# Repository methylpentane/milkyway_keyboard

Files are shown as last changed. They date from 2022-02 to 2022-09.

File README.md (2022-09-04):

# milkyway 65% keyboard pcb & plate
This repository contains kicad file (PCB/schematic), no firmware here.

This repository based on [GL516 Design Template](https://github.com/Salicylic-acid3/GL516_Template) by Salicylic-acid3.

# feature
- 65% keyboard that neatly looks like Tsangan-layout.
- Several layout options on center area(milkyway-area).
    - macro
    - rotary encoders
    - numpad (with sacrificing symbol keys on righthand)
- Also there will be some layout options on R5.
    - split spacebars
    - one more rotary encoder
    - 8u & 10u spacebar 🤔

# supported layout
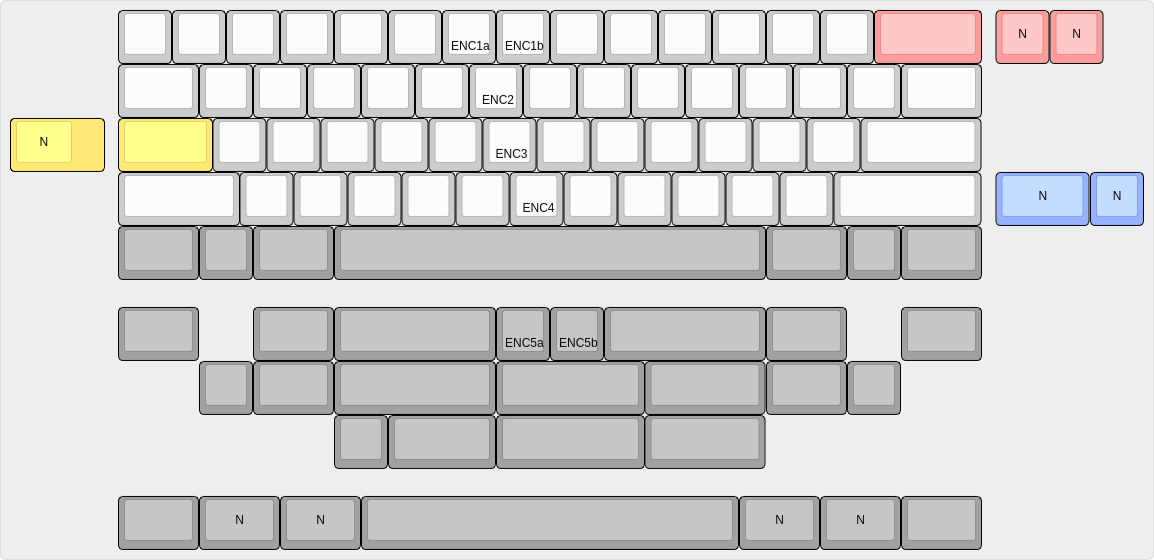
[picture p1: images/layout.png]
layout

- about keys that have "ENC" written, you can choose whether to implement keyswitch or encoder.
    - For ENC1a and ENC1b, only one of the encoders can be implemented. and the same for ENC5a and ENC5b.
- some layouts force northfacing switch (switch with "N")

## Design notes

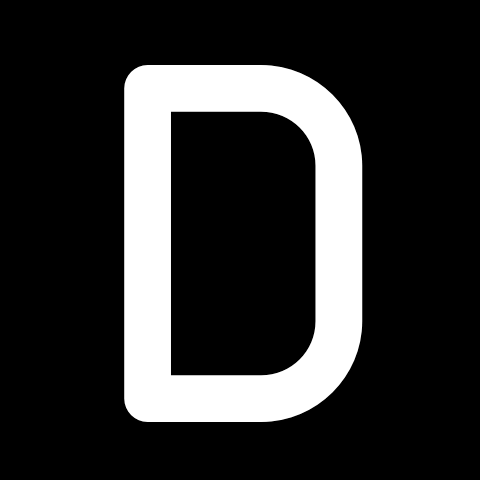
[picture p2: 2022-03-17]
images/D_label.png

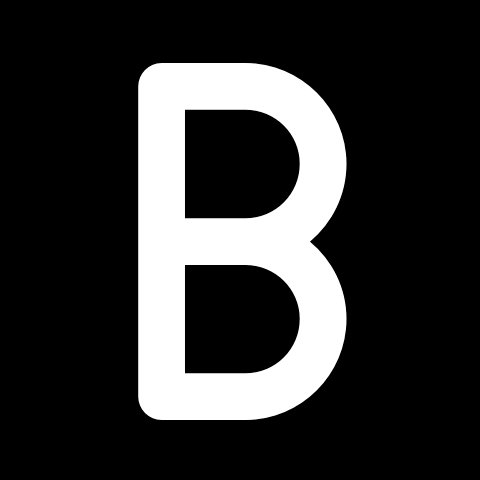
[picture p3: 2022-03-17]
images/B_label.png

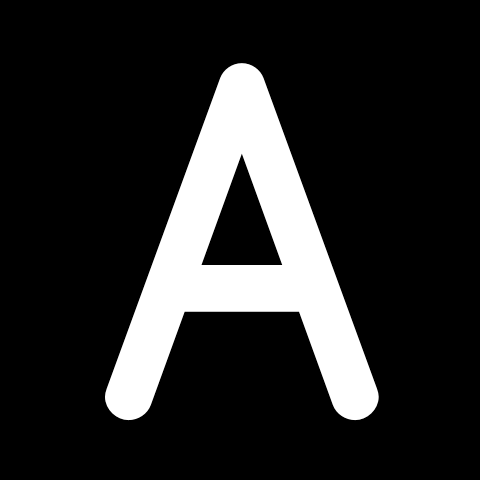
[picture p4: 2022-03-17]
images/A_label.png

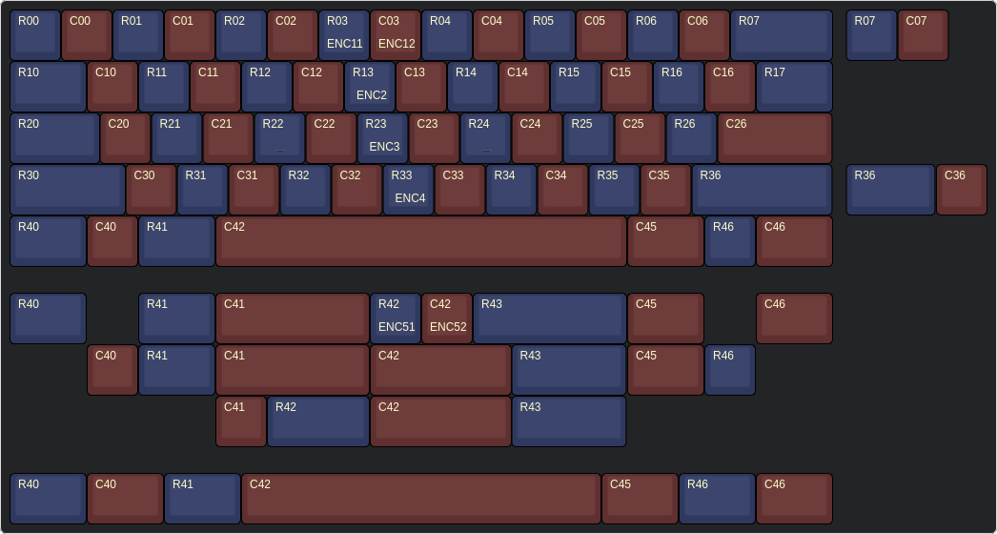
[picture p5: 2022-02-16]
images/layout_for_dev.png

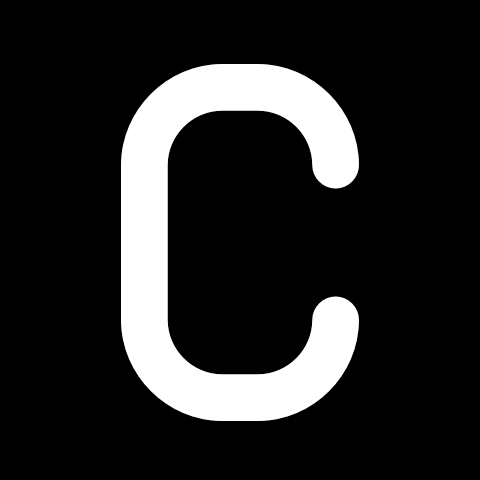
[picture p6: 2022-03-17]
images/C_label.png

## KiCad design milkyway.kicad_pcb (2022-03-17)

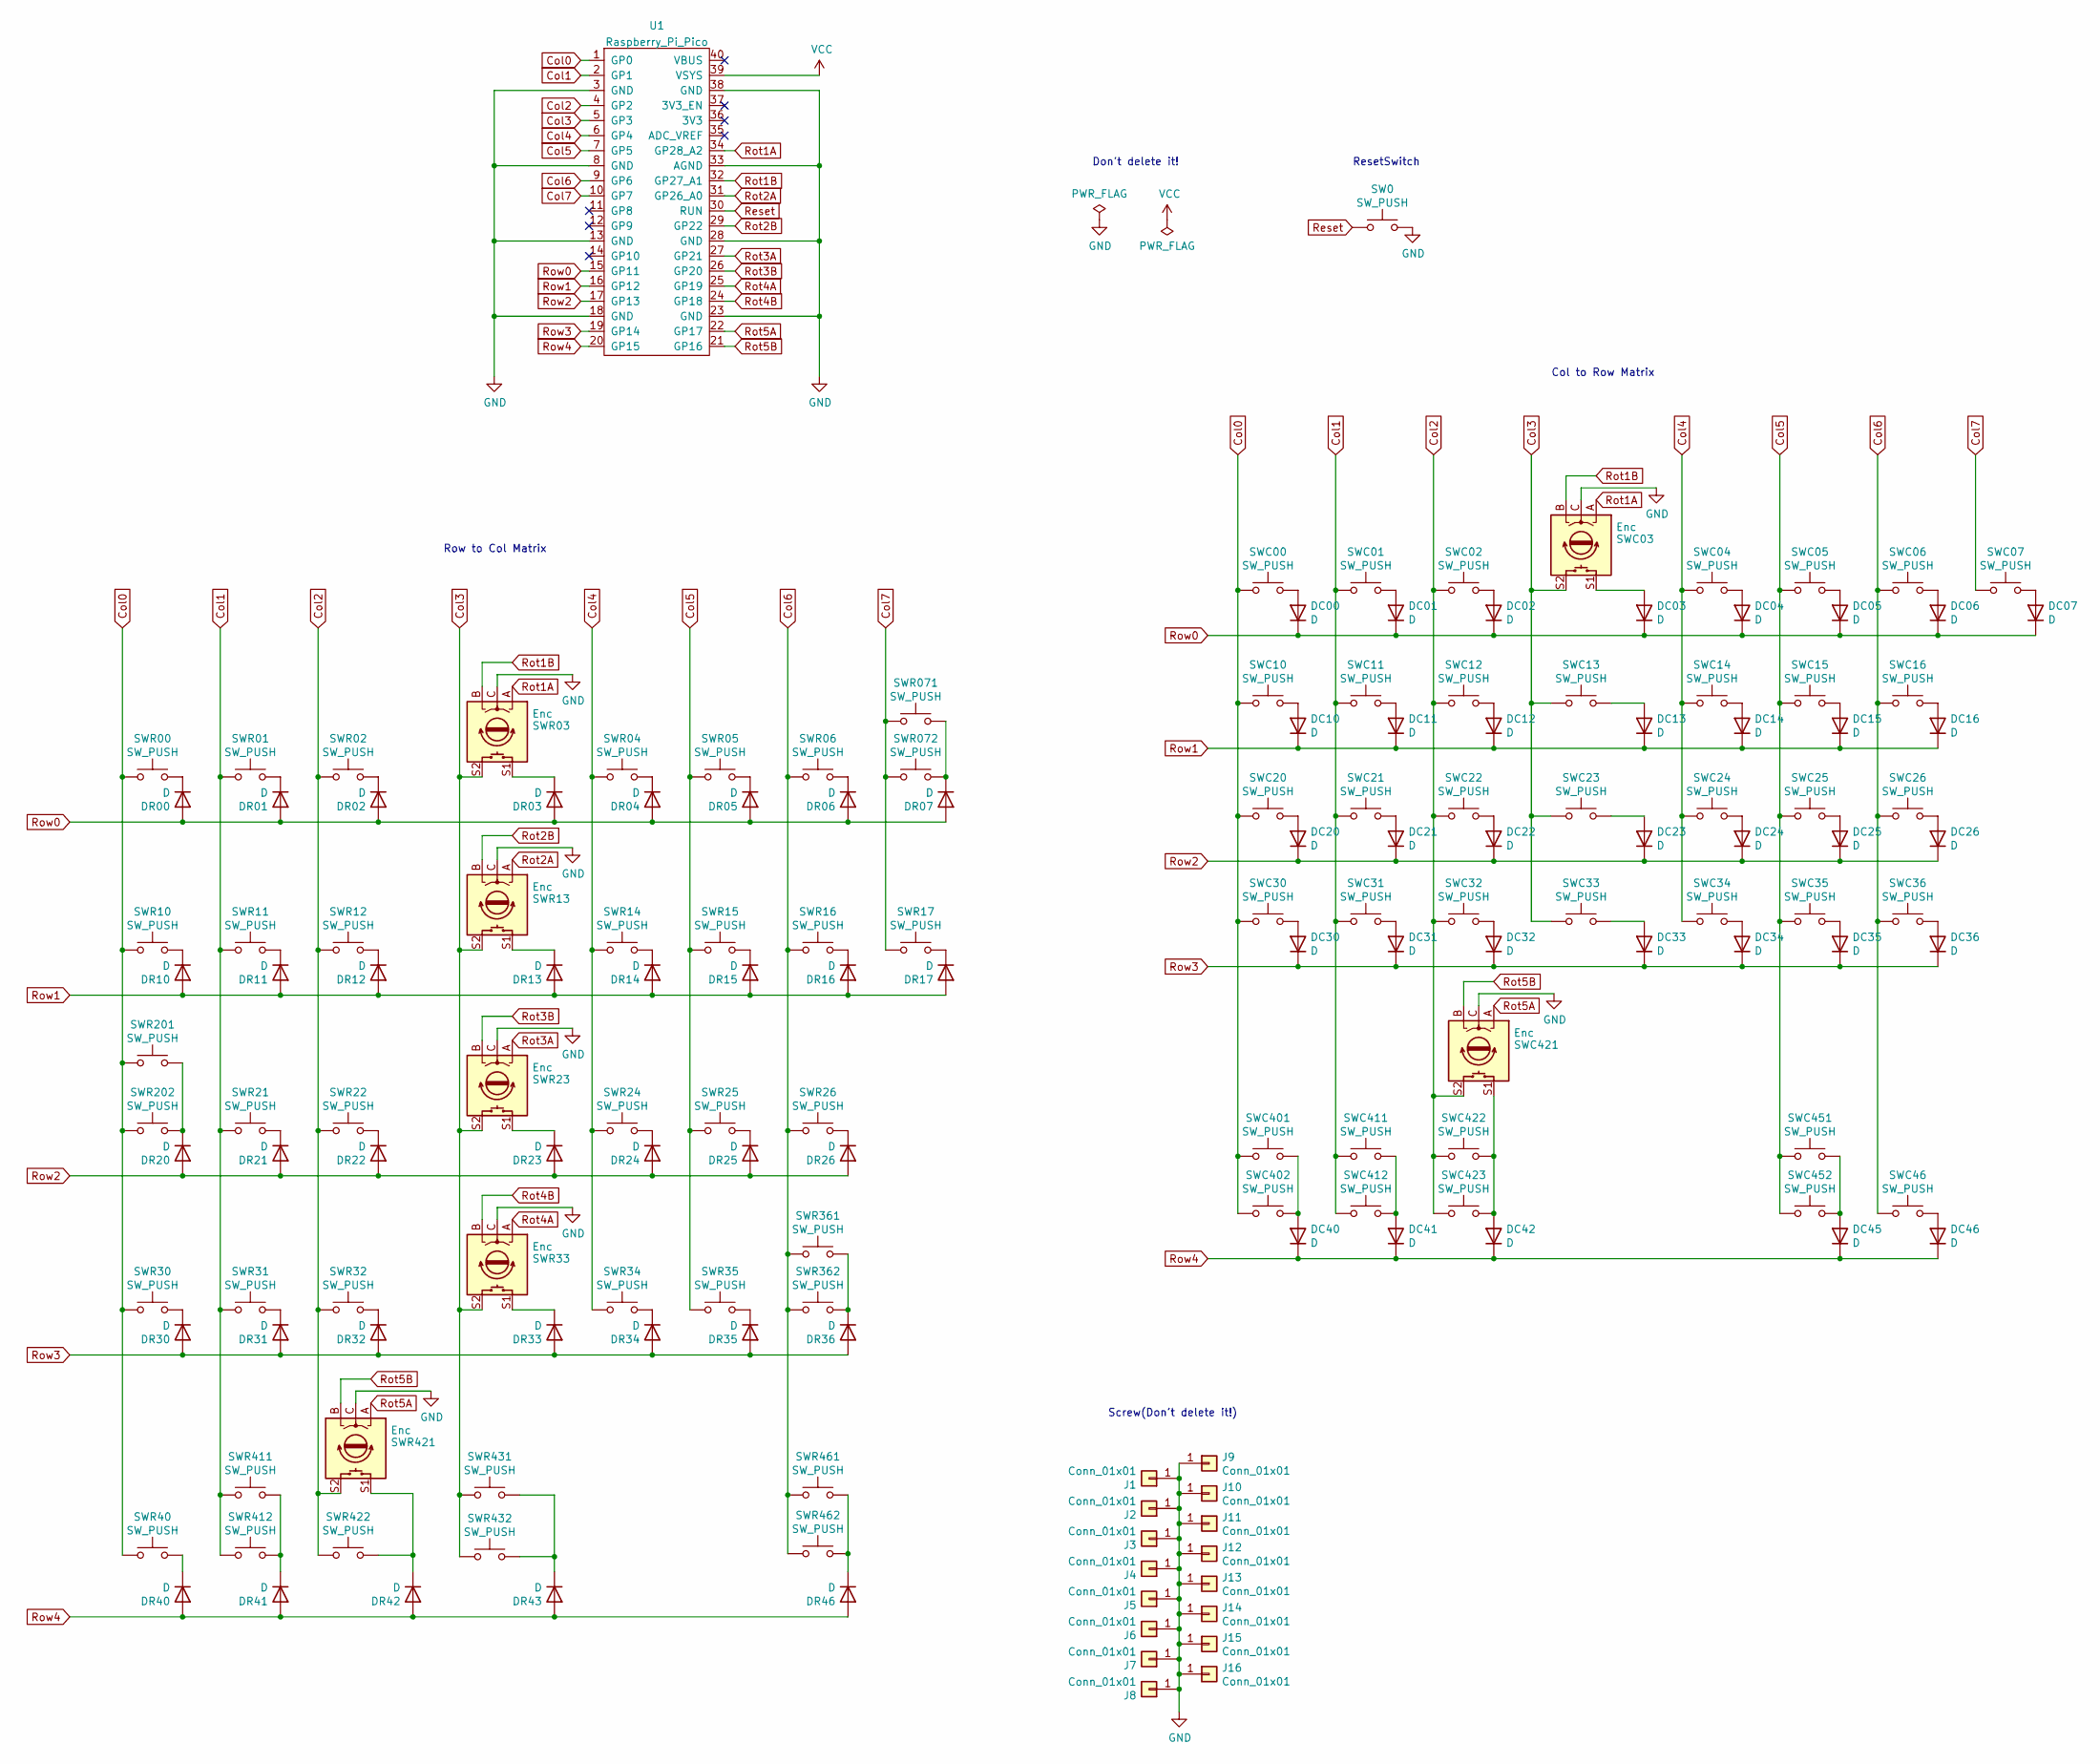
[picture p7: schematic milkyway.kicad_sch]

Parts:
DC00, DC01, DC02, DC03, DC04, DC05, DC06, DC07, DC10, DC11, DC12, DC13, DC14, DC15, DC16, DC20, DC21, DC22, DC23, DC24, DC25, DC26, DC30, DC31, DC32, DC33, DC34, DC35, DC36, DC40, DC41, DC42, DC45, DC46: D; Diode_TH_SMD
DR00, DR01, DR02, DR03, DR04, DR05, DR06, DR07, DR10, DR11, DR12, DR13, DR14, DR15, DR16, DR17, DR20, DR21, DR22, DR23, DR24, DR25, DR26, DR30, DR31, DR32, DR33, DR34, DR35, DR36, DR40, DR41, DR42, DR43, DR46: D; Diode_TH_SMD
J1, J2, J3, J4, J5, J6: Conn_01x01; m2_Screw_Hole_EdgeCuts
J7, J8, J9, J10, J11, J12, J13, J14, J15, J16: Conn_01x01; m2_Screw_Hole_Fab
SW0: SW_PUSH; ResetSW
SWC00, SWC01, SWC02, SWC04, SWC05, SWC06, SWC07, SWC10, SWC11, SWC12, SWC13, SWC14, SWC15, SWC16, SWC20, SWC21, SWC22, SWC23, SWC24, SWC25, SWC30, SWC31, SWC32, SWC33, SWC34, SWC35, SWC36, SWC401: SW_PUSH; CherryMX_Hotswap_1u
SWC03: Enc; CherryMX_Hotswap_1u_EC12
SWC26: SW_PUSH; CherryMX_Hotswap_2.25u
SWC46, SWC402, SWC451, SWC452: SW_PUSH; CherryMX_Hotswap_1.5u
SWC411: SW_PUSH; CherryMX_Solder_3u_Rev
SWC412: SW_PUSH; CherryMX_1u_solder
SWC421: Enc; CherryMX_Solder_1u_EC12
SWC422: SW_PUSH; CherryMX_Solder_8u7u_Rev
SWC423: SW_PUSH; CherryMX_Solder_2.75u_Rev
SWR00, SWR01, SWR02, SWR04, SWR05, SWR06, SWR11, SWR12, SWR14, SWR15, SWR16, SWR21, SWR22, SWR24, SWR25, SWR26, SWR31, SWR32, SWR34, SWR35, SWR072, SWR202, SWR461: SW_PUSH; CherryMX_Hotswap_1u
SWR03, SWR13, SWR23, SWR33: Enc; CherryMX_Hotswap_1u_EC12
SWR10, SWR17, SWR40, SWR411, SWR412, SWR462: SW_PUSH; CherryMX_Hotswap_1.5u
SWR30, SWR361: SW_PUSH; CherryMX_Hotswap_2.75u
SWR071: SW_PUSH; CherryMX_Hotswap_2u
SWR201, SWR362: SW_PUSH; CherryMX_Hotswap_1.75u
SWR421: Enc; CherryMX_Solder_1u_EC12
SWR422: SW_PUSH; CherryMX_Solder_2u_Rev
SWR431: SW_PUSH; CherryMX_Solder_3u_Rev
SWR432: SW_PUSH; CherryMX_Solder_2.25u_Rev
U1: Raspberry_Pi_Pico

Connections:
Col0: SWC00.1, SWC10.1, SWC20.1, SWC30.1, SWC401.1, SWC402.1, SWR00.1, SWR10.1, SWR30.1, SWR40.1, SWR201.1, SWR202.1, U1.1 (GP0)
Col1: SWC01.1, SWC11.1, SWC21.1, SWC31.1, SWC411.1, SWC412.1, SWR01.1, SWR11.1, SWR21.1, SWR31.1, SWR411.1, SWR412.1, U1.2 (GP1)
Col2: SWC02.1, SWC12.1, SWC22.1, SWC32.1, SWC421.S2, SWC422.1, SWC423.1, SWR02.1, SWR12.1, SWR22.1, SWR32.1, SWR421.S2, SWR422.1, U1.4 (GP2)
Col3: SWC03.S2, SWC13.1, SWC23.1, SWC33.1, SWR03.S2, SWR13.S2, SWR23.S2, SWR33.S2, SWR431.1, SWR432.1, U1.5 (GP3)
Col4: SWC04.1, SWC14.1, SWC24.1, SWC34.1, SWR04.1, SWR14.1, SWR24.1, SWR34.1, U1.6 (GP4)
Col5: SWC05.1, SWC15.1, SWC25.1, SWC35.1, SWC451.1, SWC452.1, SWR05.1, SWR15.1, SWR25.1, SWR35.1, U1.7 (GP5)
Col6: SWC06.1, SWC16.1, SWC26.1, SWC36.1, SWC46.1, SWR06.1, SWR16.1, SWR26.1, SWR361.1, SWR362.1, SWR461.1, SWR462.1, U1.9 (GP6)
Col7: SWC07.1, SWR17.1, SWR071.1, SWR072.1, U1.10 (GP7)
GND: J1.1, J2.1, J3.1, J4.1, J5.1, J6.1, J7.1, J8.1, J9.1, J10.1, J11.1, J12.1, J13.1, J14.1, J15.1, J16.1, SW0.2, SWC03.C, SWC421.C, SWR03.C, SWR13.C, SWR23.C, SWR33.C, SWR421.C, U1.3 (GND), U1.8 (GND), U1.13 (GND), U1.18 (GND), U1.23 (GND), U1.28 (GND), U1.33 (AGND), U1.38 (GND)
unnamed: DC00.2 (A), SWC00.2
unnamed: DC01.2 (A), SWC01.2
unnamed: DC02.2 (A), SWC02.2
unnamed: DC03.2 (A), SWC03.S1
unnamed: DC04.2 (A), SWC04.2
unnamed: DC05.2 (A), SWC05.2
unnamed: DC06.2 (A), SWC06.2
unnamed: DC07.2 (A), SWC07.2
unnamed: DC10.2 (A), SWC10.2
unnamed: DC11.2 (A), SWC11.2
unnamed: DC12.2 (A), SWC12.2
unnamed: DC13.2 (A), SWC13.2
unnamed: DC14.2 (A), SWC14.2
unnamed: DC15.2 (A), SWC15.2
unnamed: DC16.2 (A), SWC16.2
unnamed: DC20.2 (A), SWC20.2
unnamed: DC21.2 (A), SWC21.2
unnamed: DC22.2 (A), SWC22.2
unnamed: DC23.2 (A), SWC23.2
unnamed: DC24.2 (A), SWC24.2
unnamed: DC25.2 (A), SWC25.2
unnamed: DC26.2 (A), SWC26.2
unnamed: DC30.2 (A), SWC30.2
unnamed: DC31.2 (A), SWC31.2
unnamed: DC32.2 (A), SWC32.2
unnamed: DC33.2 (A), SWC33.2
unnamed: DC34.2 (A), SWC34.2
unnamed: DC35.2 (A), SWC35.2
unnamed: DC36.2 (A), SWC36.2
unnamed: DC40.2 (A), SWC401.2, SWC402.2
unnamed: DC41.2 (A), SWC411.2, SWC412.2
unnamed: DC42.2 (A), SWC421.S1, SWC422.2, SWC423.2
unnamed: DC45.2 (A), SWC451.2, SWC452.2
unnamed: DC46.2 (A), SWC46.2
unnamed: DR00.1 (K), SWR00.2
unnamed: DR01.1 (K), SWR01.2
unnamed: DR02.1 (K), SWR02.2
unnamed: DR03.1 (K), SWR03.S1
unnamed: DR04.1 (K), SWR04.2
unnamed: DR05.1 (K), SWR05.2
unnamed: DR06.1 (K), SWR06.2
unnamed: DR07.1 (K), SWR071.2, SWR072.2
unnamed: DR10.1 (K), SWR10.2
unnamed: DR11.1 (K), SWR11.2
unnamed: DR12.1 (K), SWR12.2
unnamed: DR13.1 (K), SWR13.S1
unnamed: DR14.1 (K), SWR14.2
unnamed: DR15.1 (K), SWR15.2
unnamed: DR16.1 (K), SWR16.2
unnamed: DR17.1 (K), SWR17.2
unnamed: DR20.1 (K), SWR201.2, SWR202.2
unnamed: DR21.1 (K), SWR21.2
unnamed: DR22.1 (K), SWR22.2
unnamed: DR23.1 (K), SWR23.S1
unnamed: DR24.1 (K), SWR24.2
unnamed: DR25.1 (K), SWR25.2
unnamed: DR26.1 (K), SWR26.2
unnamed: DR30.1 (K), SWR30.2
unnamed: DR31.1 (K), SWR31.2
unnamed: DR32.1 (K), SWR32.2
unnamed: DR33.1 (K), SWR33.S1
unnamed: DR34.1 (K), SWR34.2
unnamed: DR35.1 (K), SWR35.2
unnamed: DR36.1 (K), SWR361.2, SWR362.2
unnamed: DR40.1 (K), SWR40.2
unnamed: DR41.1 (K), SWR411.2, SWR412.2
unnamed: DR42.1 (K), SWR421.S1, SWR422.2
unnamed: DR43.1 (K), SWR431.2, SWR432.2
unnamed: DR46.1 (K), SWR461.2, SWR462.2
Reset: SW0.1, U1.30 (RUN)
Rot1A: SWC03.A, SWR03.A, U1.34 (GP28_A2)
Rot1B: SWC03.B, SWR03.B, U1.32 (GP27_A1)
Rot2A: SWR13.A, U1.31 (GP26_A0)
Rot2B: SWR13.B, U1.29 (GP22)
Rot3A: SWR23.A, U1.27 (GP21)
Rot3B: SWR23.B, U1.26 (GP20)
Rot4A: SWR33.A, U1.25 (GP19)
Rot4B: SWR33.B, U1.24 (GP18)
Rot5A: SWC421.A, SWR421.A, U1.22 (GP17)
Rot5B: SWC421.B, SWR421.B, U1.21 (GP16)
Row0: DC00.1 (K), DC01.1 (K), DC02.1 (K), DC03.1 (K), DC04.1 (K), DC05.1 (K), DC06.1 (K), DC07.1 (K), DR00.2 (A), DR01.2 (A), DR02.2 (A), DR03.2 (A), DR04.2 (A), DR05.2 (A), DR06.2 (A), DR07.2 (A), U1.15 (GP11)
Row1: DC10.1 (K), DC11.1 (K), DC12.1 (K), DC13.1 (K), DC14.1 (K), DC15.1 (K), DC16.1 (K), DR10.2 (A), DR11.2 (A), DR12.2 (A), DR13.2 (A), DR14.2 (A), DR15.2 (A), DR16.2 (A), DR17.2 (A), U1.16 (GP12)
Row2: DC20.1 (K), DC21.1 (K), DC22.1 (K), DC23.1 (K), DC24.1 (K), DC25.1 (K), DC26.1 (K), DR20.2 (A), DR21.2 (A), DR22.2 (A), DR23.2 (A), DR24.2 (A), DR25.2 (A), DR26.2 (A), U1.17 (GP13)
Row3: DC30.1 (K), DC31.1 (K), DC32.1 (K), DC33.1 (K), DC34.1 (K), DC35.1 (K), DC36.1 (K), DR30.2 (A), DR31.2 (A), DR32.2 (A), DR33.2 (A), DR34.2 (A), DR35.2 (A), DR36.2 (A), U1.19 (GP14)
Row4: DC40.1 (K), DC41.1 (K), DC42.1 (K), DC45.1 (K), DC46.1 (K), DR40.2 (A), DR41.2 (A), DR42.2 (A), DR43.2 (A), DR46.2 (A), U1.20 (GP15)
VCC: U1.39 (VSYS)

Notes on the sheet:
Screw(Don't delete it!)
Don't delete it!
ResetSwitch
Row to Col Matrix
Col to Row Matrix

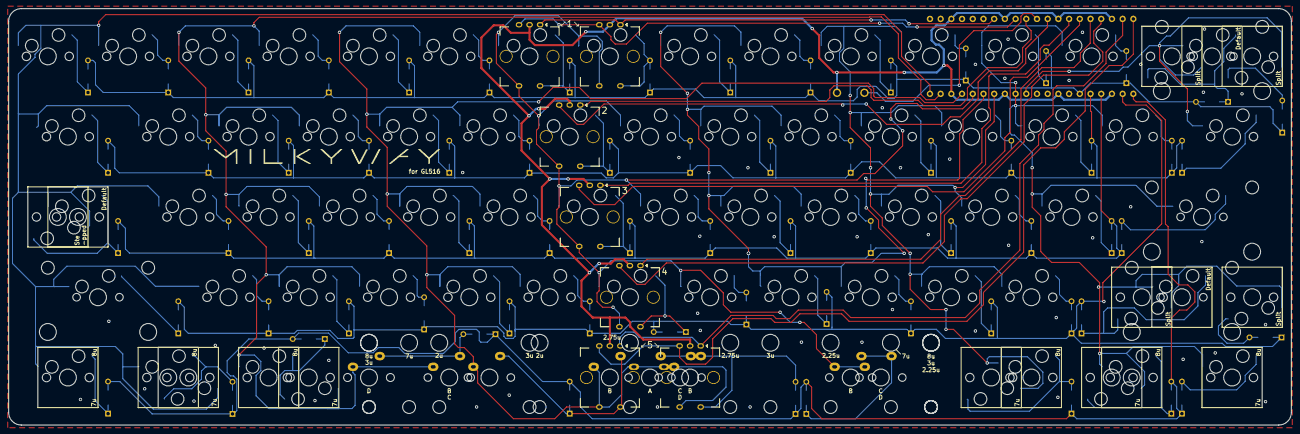
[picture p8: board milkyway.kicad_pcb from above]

Board: 2 copper layers, 304.4 x 98.8 mm, 162 parts (0 on the bottom side), 94 nets.

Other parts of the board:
J17: Conn_01x01; m2_Screw_Hole_Fab

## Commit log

2022-02-06 first commit .
    [GL516_Template.kicad_pcb, GL516_Template.sch]
2022-02-09 complete plate
    [milkyway.kicad_pcb]
2022-02-16 complete pcb
    [milkyway.kicad_pcb, milkyway.kicad_sch, milkyway_plate.kicad_pcb]
2022-02-16 スタビバー上を通る配線を修正
    [milkyway.kicad_pcb]
2022-02-16 画像を修正
2022-02-17 プレートのkicad_proが増えた
2022-02-17 add decoration plate template
    [milkyway_deco.kicad_pcb]
2022-02-18 footprint miss thx salicylic acid san
    [milkyway.kicad_pcb]
2022-02-18 pipicoフットプリント修正 配線かっこよく
    [milkyway.kicad_pcb]
2022-02-18 追加調整
    [milkyway.kicad_pcb]
2022-02-20 さらに追加調整
    [milkyway.kicad_pcb]
2022-02-20 さらにさらに追加調整
    [milkyway.kicad_pcb]
2022-02-21 組み立て補助のためのシルク調整
    [milkyway.kicad_pcb]
2022-02-21 image directory. design logo on back. front soon.
    [milkyway.kicad_pcb]
2022-02-21 front silk design
    [milkyway.kicad_pcb]
2022-02-22 配線クリアランス完全確保 GNDベタ Stepped CapsLock修正
2022-02-22 Stepped CapsLock修正(plate)
    [milkyway_plate.kicad_pcb]
2022-02-23 README 更新
2022-03-02 マスクの微修正 GNDベタ 一旦削除
2022-03-17 シルク完了、一旦完成。 カットデータ作成したが、現状ignore
    [milkyway.kicad_pcb, milkyway_plate.kicad_pcb]
